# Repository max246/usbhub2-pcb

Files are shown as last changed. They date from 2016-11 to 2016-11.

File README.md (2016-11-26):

# USBHUB version 2 PCB

I have made a preview one with another chip, which ended up to be too complicated for my purpose, it worked but this has less components to solder.
This version has 2 mosfet which needs to be connected to a pin 5V or just removed from the schematic. It was for my personal project but no needed if you need a normal usb hub.

The schematic was inspired by: https://github.com/richardhawthorn/piZero-Hub

I used SI2301CDS-T1-E3  as Mosfet to make sure there can handle enough Ampere.

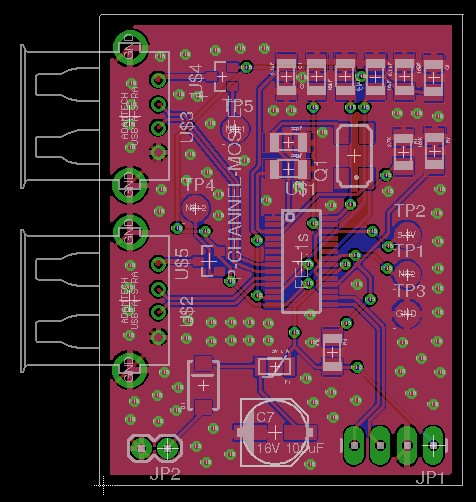
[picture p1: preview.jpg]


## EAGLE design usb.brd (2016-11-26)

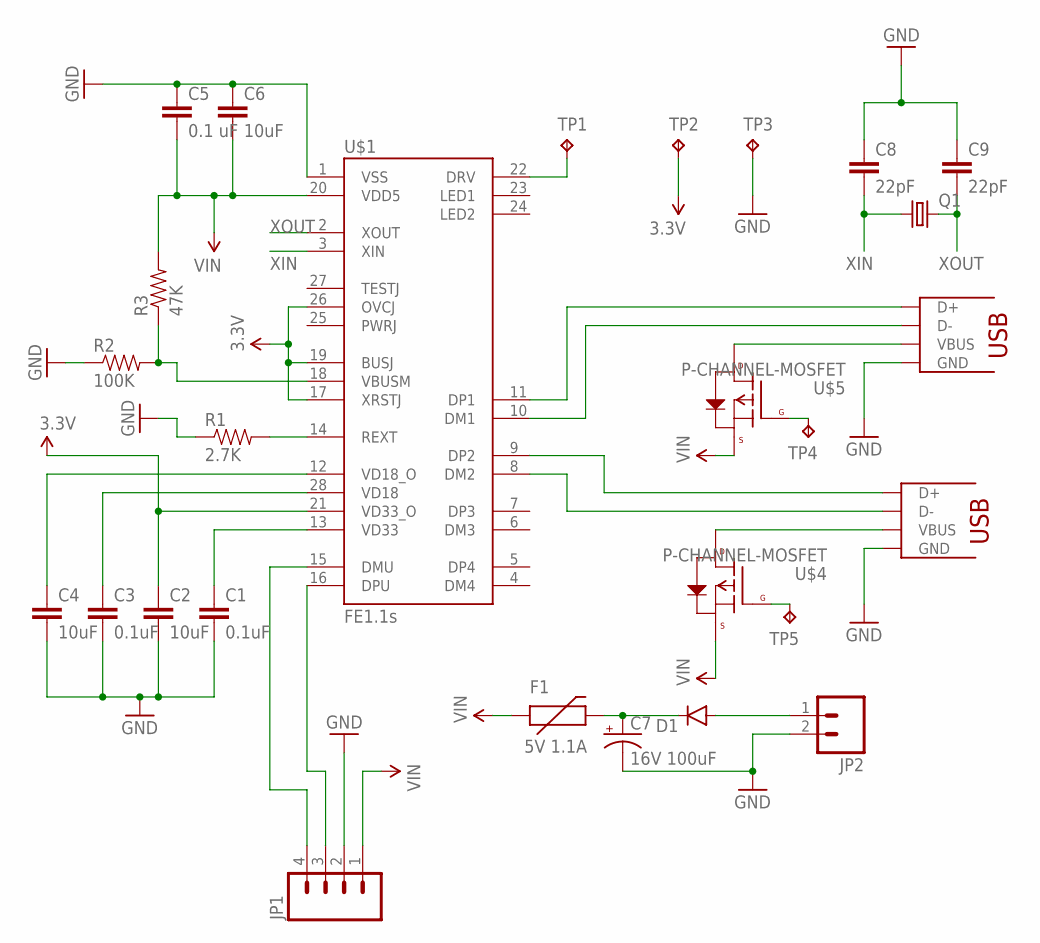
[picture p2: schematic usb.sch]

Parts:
C1, C3: 0.1uF; 1206; MPN CGA5L2C0G1H104J160AA
C2, C4, C6: 10uF; 1206; MPN GMK316F106ZL-T
C5: 0.1 uF; 1206; MPN CGA5L2C0G1H104J160AA
C7: 16V 100uF; PANASONIC_D; MPN EEEHA1C101WP
C8, C9: 22pF; 1206; MPN 12061A220JAT2A
D1: DIODESMA; SMA-DIODE; MPN SMAJ5.0A
F1: 5V 1.1A; PTC-1206
JP1: M04LONGPADS; 1X04_LONGPADS
JP2: M02PTH; 1X02
Q1: CRYSTALCTS406; CTS406; MPN ABM3B-12.000MHZ-B2-T
R1: 2.7K; 1206; MPN WCR1206-2K7FI
R2: 100K; 1206; MPN CRCW1206100KFKEA
R3: 47K; 1206; MPN CRCW120647K0FKEA
TP1, TP2, TP3, TP4, TP5: TP_DRV; B2,54
U$1: FE1.1S; FE1.1S_SSOP-28
U$2, U$3: USB-A-S; USB-A-S-RA-PTH
U$4, U$5: P-CHANNEL-MOSFET; SOT23-3; MPN SI2301CDS-T1-E3

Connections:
3.3V: C2.1, TP2.TP, U$1.17 (XRSTJ), U$1.19 (BUSJ), U$1.21 (VD33_O), U$1.26 (OVCJ)
GND: C1.2, C2.2, C3.2, C4.2, C5.1, C6.1, C7.-, C8.1, C9.1, JP1.2, JP2.2, R1.1, R2.1, TP3.TP, U$1.1 (VSS), U$2.GND, U$2.GND2 (GND), U$2.GND3 (GND), U$3.GND, U$3.GND2 (GND), U$3.GND3 (GND)
unnamed: C1.1, U$1.13 (VD33)
unnamed: TP1.TP, U$1.22 (DRV)
unnamed: C3.1, U$1.28 (VD18)
unnamed: C4.1, U$1.12 (VD18_O)
unnamed: D1.A, JP2.1
unnamed: C7.+, D1.C, F1.2
unnamed: R1.2, U$1.14 (REXT)
unnamed: U$3.VBUS, U$4.3 (D)
unnamed: R2.2, R3.1, U$1.18 (VBUSM)
unnamed: U$2.VBUS, U$5.3 (D)
unnamed: TP5.TP, U$4.1 (G)
unnamed: TP4.TP, U$5.1 (G)
USB1_N: U$1.10 (DM1), U$2.D-
USB1_P: U$1.11 (DP1), U$2.D+
USB2_N: U$1.8 (DM2), U$3.D-
USB2_P: U$1.9 (DP2), U$3.D+
USBIN_N: JP1.4, U$1.15 (DMU)
USBIN_P: JP1.3, U$1.16 (DPU)
VIN: C5.2, C6.2, F1.1, JP1.1, R3.2, U$1.20 (VDD5), U$4.2 (S), U$5.2 (S)
XIN: C8.2, Q1.1, U$1.3 (XIN)
XOUT: C9.2, Q1.3 (2), U$1.2 (XOUT)

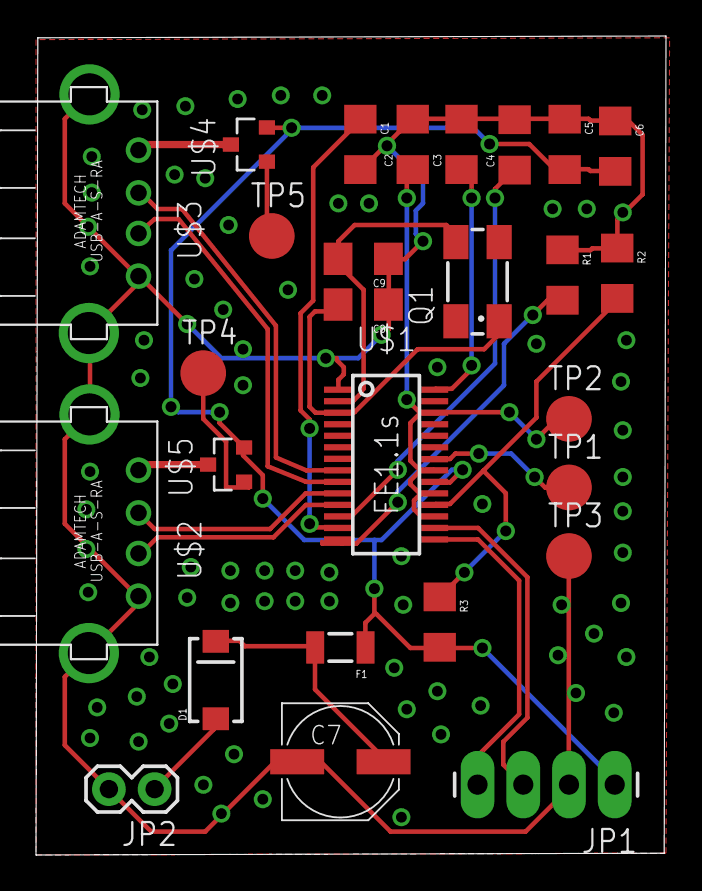
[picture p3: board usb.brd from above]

Board: 2 copper layers, 35.0 x 45.5 mm, 27 parts (0 on the bottom side), 23 nets.

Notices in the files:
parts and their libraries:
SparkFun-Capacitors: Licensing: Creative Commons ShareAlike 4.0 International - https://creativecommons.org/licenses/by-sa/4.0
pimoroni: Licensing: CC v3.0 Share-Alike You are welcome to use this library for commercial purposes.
